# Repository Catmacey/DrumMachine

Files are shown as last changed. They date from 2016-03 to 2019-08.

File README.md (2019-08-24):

16 step sample based DrumMachine
================================

DrumMachine

[Demo of features (Youtube)](https://www.youtube.com/watch?v=TWu0VHxkMRI)

This is a 16 track Sample based Drum Machine built on a 32bit PIC (PIC32mx150f128b).

The project hardware is relatively simple in that it limits itself to using the PIC's internal Flash for sample storage and the built in OC PWM for output. 

The Drum Machine has 16 tracks (instruments) of 16 steps and can save the song to one of 16 slots on a uSD card.

Features : Updated 24 / 8 / 2019

* 16 different instruments stored in Flash (Length dependant on sample quality/size).
* 16 step patterns with 16 patterns per song.
* 16 songs loaded and saved to FAT formatted uSD card.
* 8 sample polyphony, mixed in software.
* 10bit, 16khz instruments sampled from classic drum machines. (stored as 8bit log similar to uLaw)
* Samples can be "tuned" to playback faster/slower, louder quieter and can also have the in/out points set.
* "Jam Mode" to add some variety to your tracks by fading in/out each track as it plays.
* Swing
* Basic Reverb mode.
* Analog mono output filtered from an 10bit PWM signal.
* 16 buttons for beat input plus 4 more and 4-way joystick for interface.
* 20 leds driven by a Maxim 6957 LED driver to provide feedback.
* [Nokia 1202 B/W LCD](https://github.com/Catmacey/Nokia1202LCD-breakout) mounted on a breakout board displays user interface.
* Songs are stored as plain text in JSON format to allow some human readability.

[More information is available on my blog.](https://catmacey.wordpress.com/tag/drum-machine/)

Copyright (C) 2016 Matt Casey : catmacey.com
This program is free software: you can redistribute it and/or modify it under the terms of the GNU General Public License as published by the Free Software Foundation, either version 3 of the License, or (at your option) any later version.
	
This program is distributed in the hope that it will be useful, but WITHOUT ANY WARRANTY; without even the implied warranty of MERCHANTABILITY or FITNESS FOR A PARTICULAR PURPOSE.  See the GNU General Public License for more details.

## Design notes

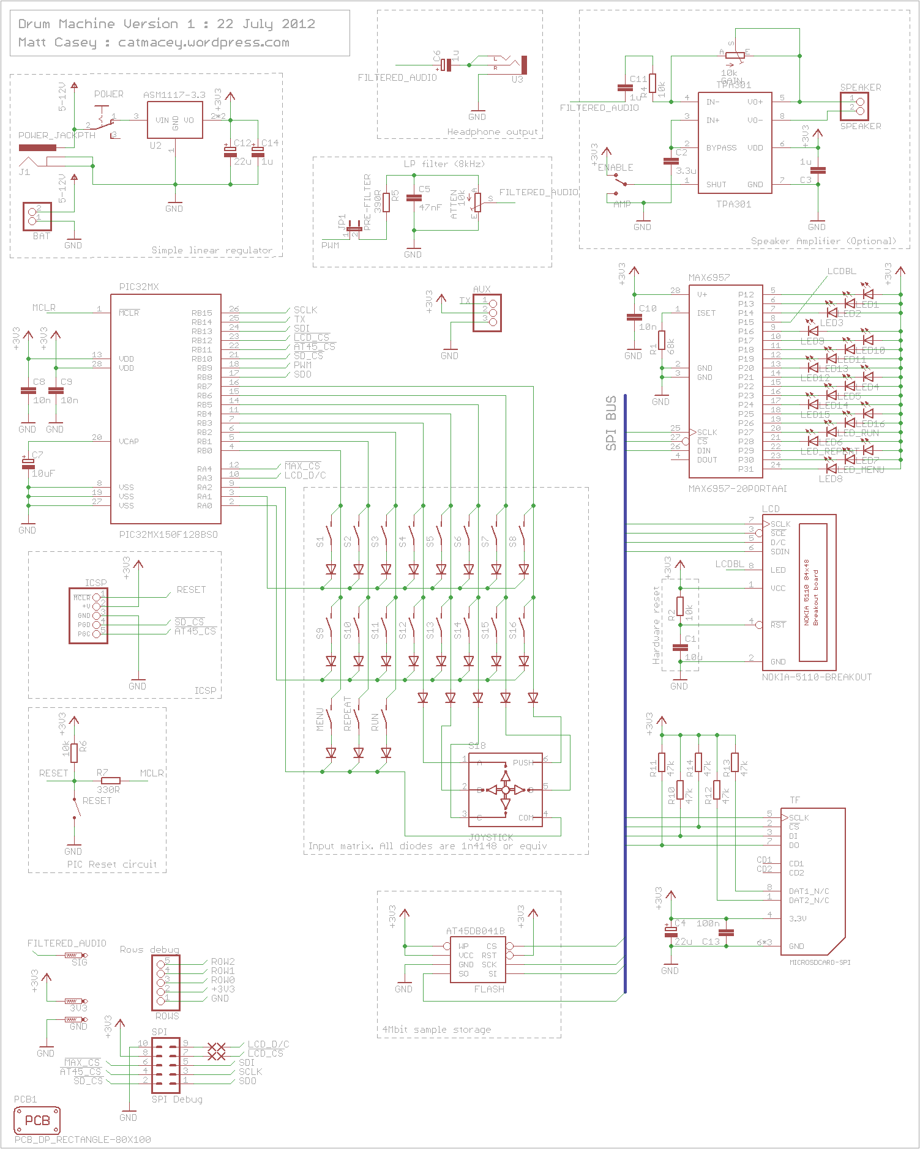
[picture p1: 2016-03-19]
EagleCad/DrumMachine_Pic32_v1.2.Schematic.png

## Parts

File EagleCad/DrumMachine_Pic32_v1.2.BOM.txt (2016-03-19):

Partlist exported from DrumMachine_Pic32_v1.2.sch at 19/03/2016 18:22:23

Part       Value                    Device                   Package                Description                                                   MF MPN OC_FARNELL OC_NEWARK TP_SIGNAL_NAME
3V3        PTR1PAD1-13              PTR1PAD1-13              P1-13                  TEST PIN                                                                                                
AMP        ENABLE                   SWITCH-SPST-SMD-A        SWITCH-SPST-SMD-A      SPST Switch                                                                                             
ATTEN      10k                      TRIM_EU-CA6V             CA6V                   POTENTIOMETER                                                                                           
AUX                                 PINHD-1X3                1X03                   PIN HEADER                                                                                              
BAT                                 PINHD-1X2                1X02                   PIN HEADER                                                                                              
C1         10u                      C-EUC0805                C0805                  CAPACITOR, European symbol                                                                              
C2         3.3u                     C-EUC0805                C0805                  CAPACITOR, European symbol                                                                              
C3         1u                       C-EUC0805                C0805                  CAPACITOR, European symbol                                                                              
C4         22u                      CPOL-EUSMCA              SMC_A                  POLARIZED CAPACITOR, European symbol                                                                    
C5         47nF                     C-EUC0805                C0805                  CAPACITOR, European symbol                                                                              
C6         1u                       CPOL-EU153CLV-0405       153CLV-0405            POLARIZED CAPACITOR, European symbol                                                                    
C7         10uF                     CPOL-EUSMCA              SMC_A                  POLARIZED CAPACITOR, European symbol                                                                    
C8         10n                      C-EUC0805                C0805                  CAPACITOR, European symbol                                                                              
C9         10n                      C-EUC0805                C0805                  CAPACITOR, European symbol                                                                              
C10        10n                      C-EUC0805                C0805                  CAPACITOR, European symbol                                                                              
C11        1u                       C-EUC0805                C0805                  CAPACITOR, European symbol                                                                              
C12        22u                      CPOL-EUSMCA              SMC_A                  POLARIZED CAPACITOR, European symbol                                                                    
C13        100n                     C-EUC0805                C0805                  CAPACITOR, European symbol                                                                              
C14        1u                       CPOL-EU153CLV-0405       153CLV-0405            POLARIZED CAPACITOR, European symbol                                                                    
D1                                  DIODE-SOD-123            SOD-123                Various Diode Packages                                                                                  
D2                                  DIODE-SOD-123            SOD-123                Various Diode Packages                                                                                  
D3                                  DIODE-SOD-123            SOD-123                Various Diode Packages                                                                                  
D4                                  DIODE-SOD-123            SOD-123                Various Diode Packages                                                                                  
D5                                  DIODE-SOD-123            SOD-123                Various Diode Packages                                                                                  
D6                                  DIODE-SOD-123            SOD-123                Various Diode Packages                                                                                  
D7                                  DIODE-SOD-123            SOD-123                Various Diode Packages                                                                                  
D8                                  DIODE-SOD-123            SOD-123                Various Diode Packages                                                                                  
D9                                  DIODE-SOD-123            SOD-123                Various Diode Packages                                                                                  
D10                                 DIODE-SOD-123            SOD-123                Various Diode Packages                                                                                  
D11                                 DIODE-SOD-123            SOD-123                Various Diode Packages                                                                                  
D12                                 DIODE-SOD-123            SOD-123                Various Diode Packages                                                                                  
D13                                 DIODE-SOD-123            SOD-123                Various Diode Packages                                                                                  
D14                                 DIODE-SOD-123            SOD-123                Various Diode Packages                                                                                  
D15                                 DIODE-SOD-123            SOD-123                Various Diode Packages                                                                                  
D16                                 DIODE-SOD-123            SOD-123                Various Diode Packages                                                                                  
D17                                 DIODE-SOD-123            SOD-123                Various Diode Packages                                                                                  
D18                                 DIODE-SOD-123            SOD-123                Various Diode Packages                                                                                  
D19                                 DIODE-SOD-123            SOD-123                Various Diode Packages                                                                                  
D20                                 DIODE-SOD-123            SOD-123                Various Diode Packages                                                                                  
D21                                 DIODE-SOD-123            SOD-123                Various Diode Packages                                                                                  
D22                                 DIODE-SOD-123            SOD-123                Various Diode Packages                                                                                  
D23                                 DIODE-SOD-123            SOD-123                Various Diode Packages                                                                                  
D25                                 DIODE-SOD-123            SOD-123                Various Diode Packages                                                                                  
FLASH      AT45DB041B               AT45DB041B               SO08                                                                                                                           
GAIN       10k                      TRIM_EU-CA6V             CA6V                   POTENTIOMETER                                                                                           
GND        PTR1PAD1-13              PTR1PAD1-13              P1-13                  TEST PIN                                                                                                
ICSP       CON_HEADER_PRG_PIC_ICSPB CON_HEADER_PRG_PIC_ICSPB HEADER_PRG_1X05_ICSP_B 5-pin PIC In Circuit Serial Programming header                                                          
J1         POWER_JACKPTH            POWER_JACKPTH            POWER_JACK_PTH         Power Jack                                                                                              
JP1        PRE-FILTER               JP1E                     JP1                    JUMPER                                                                                                  
LCD        NOKIA-5110-BREAKOUT      NOKIA-5110-BREAKOUT      NOKIA-5110-BREAKOUT                                                                                                            
LED1                                LEDCHIPLED_0805          CHIPLED_0805           LED                                                                                                     
LED2                                LEDCHIPLED_0805          CHIPLED_0805           LED                                                                                                     
LED3                                LEDCHIPLED_0805          CHIPLED_0805           LED                                                                                                     
LED4                                LEDCHIPLED_0805          CHIPLED_0805           LED                                                                                                     
LED5                                LEDCHIPLED_0805          CHIPLED_0805           LED                                                                                                     
LED6                                LEDCHIPLED_0805          CHIPLED_0805           LED                                                                                                     
LED7                                LEDCHIPLED_0805          CHIPLED_0805           LED                                                                                                     
LED8                                LEDCHIPLED_0805          CHIPLED_0805           LED                                                                                                     
LED9                                LEDCHIPLED_0805          CHIPLED_0805           LED                                                                                                     
LED10                               LEDCHIPLED_0805          CHIPLED_0805           LED                                                                                                     
LED11                               LEDCHIPLED_0805          CHIPLED_0805           LED                                                                                                     
LED12                               LEDCHIPLED_0805          CHIPLED_0805           LED                                                                                                     
LED13                               LEDCHIPLED_0805          CHIPLED_0805           LED                                                                                                     
LED14                               LEDCHIPLED_0805          CHIPLED_0805           LED                                                                                                     
LED15                               LEDCHIPLED_0805          CHIPLED_0805           LED                                                                                                     
LED16                               LEDCHIPLED_0805          CHIPLED_0805           LED                                                                                                     
LED_MENU                            LEDCHIPLED_0805          CHIPLED_0805           LED                                                                                                     
LED_REPEAT                          LEDCHIPLED_0805          CHIPLED_0805           LED                                                                                                     
LED_RUN                             LEDCHIPLED_0805          CHIPLED_0805           LED                                                                                                     
MAX6957    MAX6957-20PORTAAI        MAX6957-20PORTAAI        SSOP28                 The MAX6957 is a compact, 4-wire (SPI) interfaced LED display                                           
MENU                                ITT-PTS645SMD            ITT-PTS645SMD          ITT SWITCH                                                                                              
P1         DEBUG_LCD_CS             1,6/0,81.2/0.5           1,2/0,5                THROUGH-HOLE PAD                                                                                        
P1A        LCD CS                   1,6/0,81.2/0.5           1,2/0,5                THROUGH-HOLE PAD                                                                                        
P2         DEBUG_LCD_D/c            1,6/0,81.2/0.5           1,2/0,5                THROUGH-HOLE PAD                                                                                        
P2A                                 1,6/0,81.2/0.5           1,2/0,5                THROUGH-HOLE PAD                                                                                        
PCB1       PCB_DP_RECTANGLE-80X100  PCB_DP_RECTANGLE-80X100  DP10080_V1             Dangerous Prototypes Standard Rectangular PCB sizes                                                     
PIC32MX    PIC32MX150F128BSO        PIC32MX150F128BSO        SO-28                                                                                                                          
POWER                               DX_MINI_SPDT             DX_MINI_SPDT_VERTICAL  SLIDING SWITCH SPDT                                                                                     
R1         68k                      R-EU_R0805               R0805                  RESISTOR, European symbol                                                                               
R2         10k                      R-EU_R0805               R0805                  RESISTOR, European symbol                                                                               
R4         10k                      R-EU_R0805               R0805                  RESISTOR, European symbol                                                                               
R5         390R                     R-EU_R0805               R0805                  RESISTOR, European symbol                                                                               
R6         10k                      R-EU_R0805               R0805                  RESISTOR, European symbol                                                                               
R7         330R                     R-EU_R0805               R0805                  RESISTOR, European symbol                                                                               
R10        47k                      R-EU_R0805               R0805                  RESISTOR, European symbol                                                                               
R11        47k                      R-EU_R0805               R0805                  RESISTOR, European symbol                                                                               
R12        47k                      R-EU_R0805               R0805                  RESISTOR, European symbol                                                                               
R13        47k                      R-EU_R0805               R0805                  RESISTOR, European symbol                                                                               
R14        47k                      R-EU_R0805               R0805                  RESISTOR, European symbol                                                                               
REPEAT                              ITT-PTS645SMD            ITT-PTS645SMD          ITT SWITCH                                                                                              
RESET                               TINY_TACTILESMD          TINY_TACTILE_SMD       DIL/CODE SWITCH                                                                                         
ROWS       Rows debug               PINHD-1X5                1X05                   PIN HEADER                                                                                              
RUN                                 ITT-PTS645SMD            ITT-PTS645SMD          ITT SWITCH                                                                                              
S1                                  ITT-PTS645SMD            ITT-PTS645SMD          ITT SWITCH                                                                                              
S2                                  ITT-PTS645SMD            ITT-PTS645SMD          ITT SWITCH                                                                                              
S3                                  ITT-PTS645SMD            ITT-PTS645SMD          ITT SWITCH                                                                                              
S4                                  ITT-PTS645SMD            ITT-PTS645SMD          ITT SWITCH                                                                                              
S5                                  ITT-PTS645SMD            ITT-PTS645SMD          ITT SWITCH                                                                                              
S6                                  ITT-PTS645SMD            ITT-PTS645SMD          ITT SWITCH                                                                                              
S7                                  ITT-PTS645SMD            ITT-PTS645SMD          ITT SWITCH                                                                                              
S8                                  ITT-PTS645SMD            ITT-PTS645SMD          ITT SWITCH                                                                                              
S9                                  ITT-PTS645SMD            ITT-PTS645SMD          ITT SWITCH                                                                                              
S10                                 ITT-PTS645SMD            ITT-PTS645SMD          ITT SWITCH                                                                                              
S11                                 ITT-PTS645SMD            ITT-PTS645SMD          ITT SWITCH                                                                                              
S12                                 ITT-PTS645SMD            ITT-PTS645SMD          ITT SWITCH                                                                                              
S13                                 ITT-PTS645SMD            ITT-PTS645SMD          ITT SWITCH                                                                                              
S14                                 ITT-PTS645SMD            ITT-PTS645SMD          ITT SWITCH                                                                                              
S15                                 ITT-PTS645SMD            ITT-PTS645SMD          ITT SWITCH                                                                                              
S16                                 ITT-PTS645SMD            ITT-PTS645SMD          ITT SWITCH                                                                                              
S18        JOYSTICK                 ALPS_SKQU_JOYSTICK       ALPS_SKQU_JOYSTICK     4 way mini joystick with center push button                                                             
SIG        PTR1PAD1-13              PTR1PAD1-13              P1-13                  TEST PIN                                                                                                
SPEAKER    SPEAKER                  PINHD-1X2                1X02                   PIN HEADER                                                                                              
SPI        SPI Debug                MA05-2                   MA05-2                 PIN HEADER                                                           unknown    unknown                 
TF         MICROSDCARD-SPI          MICROSDCARD-SPI          TCF001_MICROSD_SOCKET                                                                                                          
TPA301     TPA301                   TPA301                   SO-08                  TPA301 350-mW Mono Class-AB Audio Amplifier                                                             
U2         ASM1117-3.3              ASM1117-3.3              SOT223                 ICP006                                                                                                  
U3                                  AUDIO-JACKPTH            STEREO_JACK3.5MM_PTH   3.5mm Audio Jack

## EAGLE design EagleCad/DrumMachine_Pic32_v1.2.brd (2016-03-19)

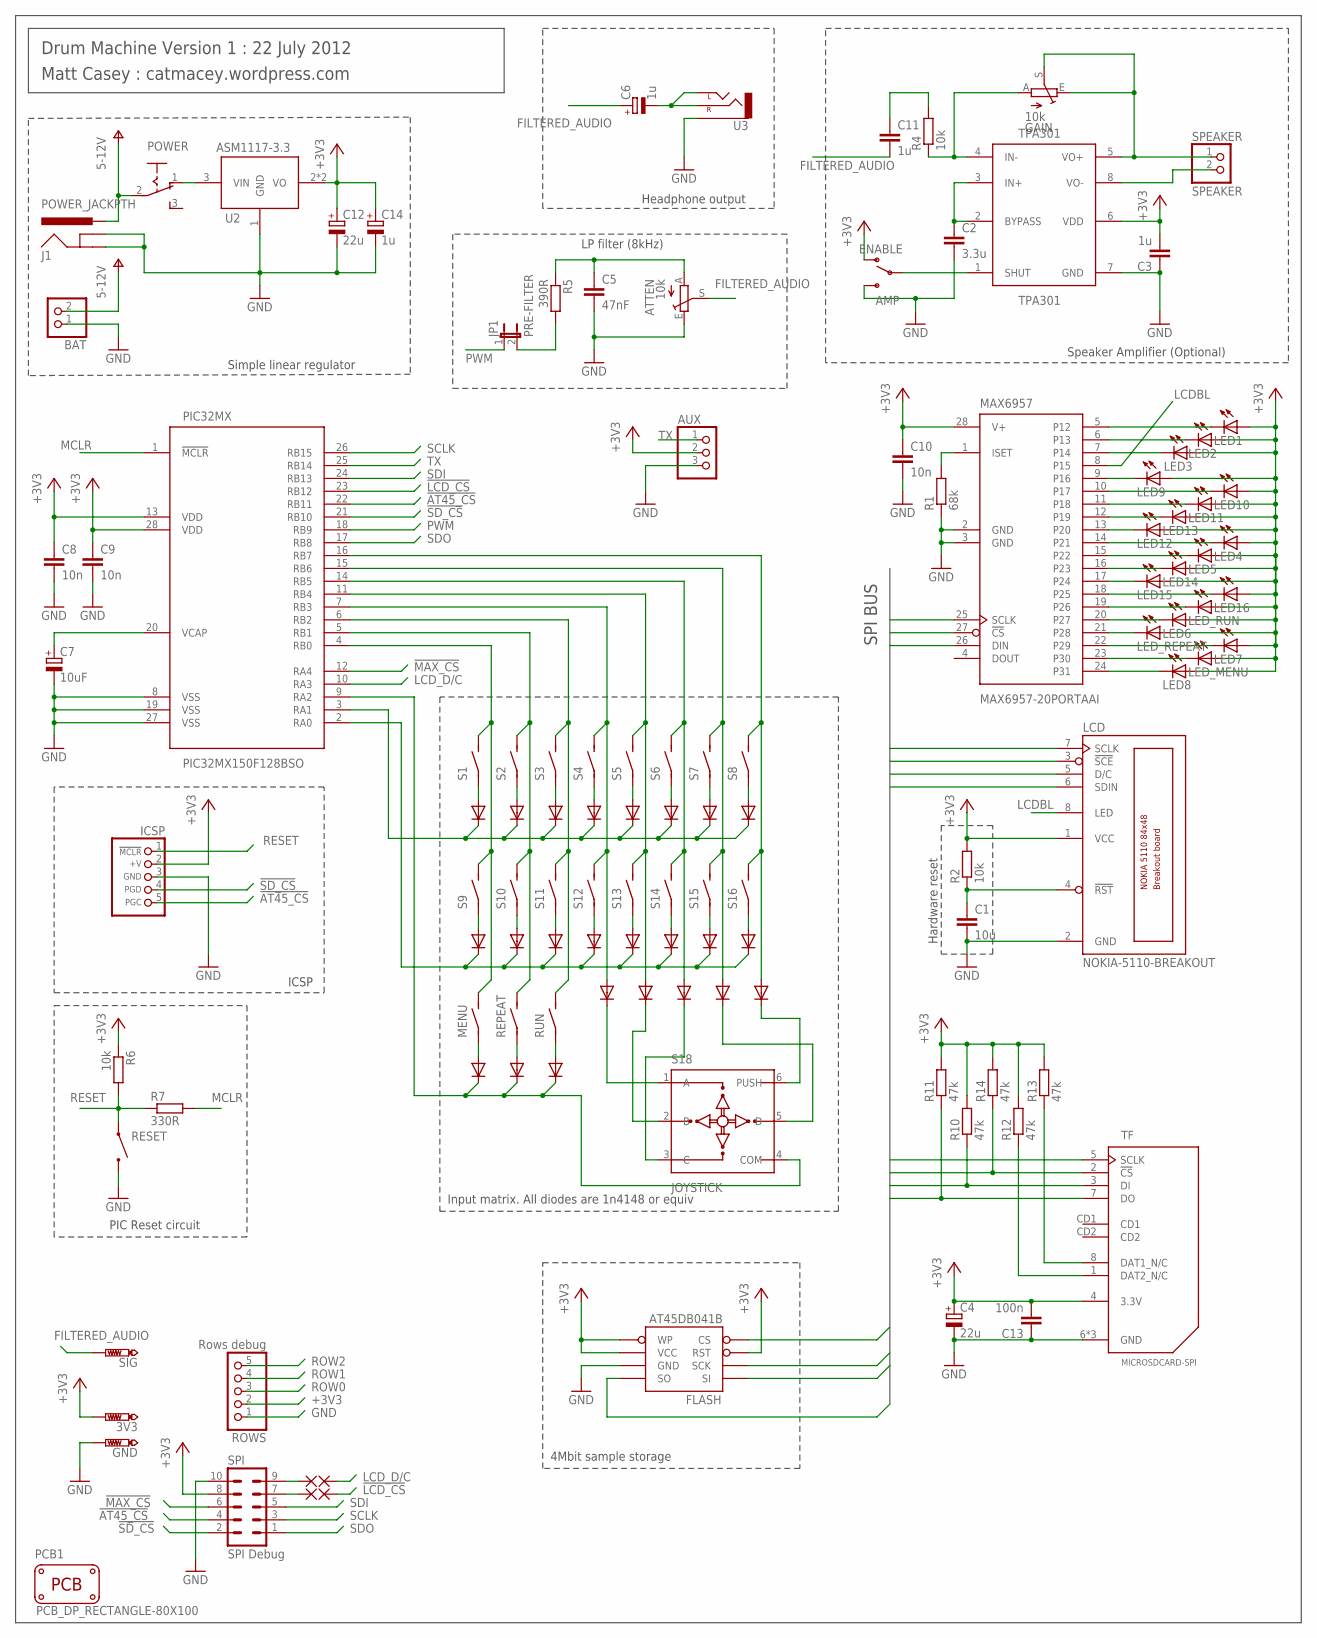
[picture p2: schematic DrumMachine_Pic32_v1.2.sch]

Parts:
3V3: PTR1PAD1-13; P1-13
AMP: ENABLE; SWITCH-SPST-SMD-A
ATTEN: 10k; CA6V
AUX: PINHD-1X3; 1X03
BAT: PINHD-1X2; 1X02
C1: 10u; C0805
C2: 3.3u; C0805
C3, C11: 1u; C0805
C4, C12: 22u; SMC_A
C5: 47nF; C0805
C6, C14: 1u; 153CLV-0405
C7: 10uF; SMC_A
C8, C9, C10: 10n; C0805
C13: 100n; C0805
D1, D2, D3, D4, D5, D6, D7, D8, D9, D10, D11, D12, D13, D14, D15, D16, D17, D18, D19, D20, D21, D22, D23, D25: DIODE-SOD-123; SOD-123
FLASH: AT45DB041B; SO08
GAIN: 10k; CA6V
GND: PTR1PAD1-13; P1-13
ICSP: CON_HEADER_PRG_PIC_ICSPB; HEADER_PRG_1X05_ICSP_B
J1: POWER_JACKPTH; POWER_JACK_PTH
JP1: PRE-FILTER; JP1
LCD: NOKIA-5110-BREAKOUT
LED1, LED2, LED3, LED4, LED5, LED6, LED7, LED8, LED9, LED10, LED11, LED12, LED13, LED14, LED15, LED16: LEDCHIPLED_0805; CHIPLED_0805
LED_MENU: LEDCHIPLED_0805; CHIPLED_0805
LED_REPEAT: LEDCHIPLED_0805; CHIPLED_0805
LED_RUN: LEDCHIPLED_0805; CHIPLED_0805
MAX6957: MAX6957-20PORTAAI; SSOP28
MENU: ITT-PTS645SMD
P1: DEBUG_LCD_CS; 1,2/0,5
P1A: LCD CS; 1,2/0,5
P2: DEBUG_LCD_D/c; 1,2/0,5
P2A: 1,6/0,81.2/0.5; 1,2/0,5
PCB1: PCB_DP_RECTANGLE-80X100; DP10080_V1
PIC32MX: PIC32MX150F128BSO; SO-28
POWER: DX_MINI_SPDT; DX_MINI_SPDT_VERTICAL
R1: 68k; R0805
R2, R4, R6: 10k; R0805
R5: 390R; R0805
R7: 330R; R0805
R10, R11, R12, R13, R14: 47k; R0805
REPEAT: ITT-PTS645SMD
RESET: TINY_TACTILESMD; TINY_TACTILE_SMD
ROWS: Rows debug; 1X05
RUN: ITT-PTS645SMD
S1, S2, S3, S4, S5, S6, S7, S8, S9, S10, S11, S12, S13, S14, S15, S16: ITT-PTS645SMD
S18: JOYSTICK; ALPS_SKQU_JOYSTICK
SIG: PTR1PAD1-13; P1-13
SPEAKER: SPEAKER; 1X02
SPI: SPI Debug; MA05-2
TF: MICROSDCARD-SPI; TCF001_MICROSD_SOCKET
TPA301: TPA301; SO-08
U2: ASM1117-3.3; SOT223
U3: AUDIO-JACKPTH; STEREO_JACK3.5MM_PTH

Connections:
!AT45_CS: FLASH.4 (CS), ICSP.5 (PGC), PIC32MX.22 (RB11), SPI.4
!LCDRST: C1.1, LCD.4 (!RST), R2.1
!LCD_CS: LCD.3 (!SCE), P1.1, P1A.1, PIC32MX.23 (RB12), SPI.7
!MAX_CS: MAX6957.27 (!CS), PIC32MX.12 (RA4), SPI.6
!SD_CS: ICSP.4 (PGD), PIC32MX.21 (RB10), R14.1, SPI.2, TF.2 (!CS)
+3V3: 3V3.TP, AMP.1 (O), AUX.2, C3.2, C4.+, C8.1, C9.1, C10.1, C12.+, C13.2, C14.+, FLASH.3 (RST), FLASH.5 (WP), FLASH.6 (VCC), ICSP.2 (+V), LCD.1 (VCC), LED1.A, LED2.A, LED3.A, LED4.A, LED5.A, LED6.A, LED7.A, LED8.A, LED9.A, LED10.A, LED11.A, LED12.A, LED13.A, LED14.A, LED15.A, LED16.A, LED_MENU.A, LED_REPEAT.A, LED_RUN.A, MAX6957.28 (V+), PIC32MX.13 (VDD), PIC32MX.28 (VDD), R2.2, R6.1, R10.2, R11.2, R12.2, R13.2, R14.2, ROWS.2, SPI.8, TF.4 (3.3V), TPA301.6 (VDD), U2.2 (VO), U2.4 (VO)
COL0: MENU.P$3 (2), MENU.P$4 (2), PIC32MX.4 (RB0), S1.P$3 (2), S1.P$4 (2), S9.P$3 (2), S9.P$4 (2)
COL1: PIC32MX.5 (RB1), REPEAT.P$3 (2), REPEAT.P$4 (2), S2.P$3 (2), S2.P$4 (2), S10.P$3 (2), S10.P$4 (2)
COL2: PIC32MX.6 (RB2), RUN.P$3 (2), RUN.P$4 (2), S3.P$3 (2), S3.P$4 (2), S11.P$3 (2), S11.P$4 (2)
COL3: D19.A, PIC32MX.7 (RB3), S4.P$3 (2), S4.P$4 (2), S12.P$3 (2), S12.P$4 (2)
COL4: D20.A, PIC32MX.11 (RB4), S5.P$3 (2), S5.P$4 (2), S13.P$3 (2), S13.P$4 (2)
COL5: D21.A, PIC32MX.14 (RB5), S6.P$3 (2), S6.P$4 (2), S14.P$3 (2), S14.P$4 (2)
COL6: D22.A, PIC32MX.15 (RB6), S7.P$3 (2), S7.P$4 (2), S15.P$3 (2), S15.P$4 (2)
COL7: D23.A, PIC32MX.16 (RB7), S8.P$3 (2), S8.P$4 (2), S16.P$3 (2), S16.P$4 (2)
FILTERED_AUDIO: ATTEN.S, C6.+, C11.2, SIG.TP
GND: AMP.3 (S), ATTEN.E, AUX.3, BAT.1, C1.2, C2.2, C3.1, C4.-, C5.2, C7.-, C8.2, C9.2, C10.2, C12.-, C13.1, C14.-, FLASH.7 (GND), GND.TP, ICSP.3 (GND), J1.GND, J1.GNDBREAK, LCD.2 (GND), MAX6957.2 (GND), MAX6957.3 (GND), PIC32MX.8 (VSS), PIC32MX.19 (VSS), PIC32MX.27 (VSS), R1.1, RESET.2 (B), ROWS.1, SPI.10, TF.6 (GND), TF.P$11 (GND), TF.P$12 (GND), TPA301.7 (GND), U2.1 (GND), U3.S (SLEEVE), U3.S@1 (SLEEVE)
LCDBL: LCD.8 (LED), MAX6957.8 (P15)
LCD_D/C: LCD.5 (D/C), P2.1, P2A.1, PIC32MX.10 (RA3), SPI.9
MCLR: PIC32MX.1 (!MCLR), R7.2
unnamed: D25.A, S1.P$1 (1), S1.P$2 (1)
unnamed: D1.A, S2.P$1 (1), S2.P$2 (1)
unnamed: D2.A, S3.P$1 (1), S3.P$2 (1)
unnamed: D3.A, S4.P$1 (1), S4.P$2 (1)
unnamed: D4.A, S5.P$1 (1), S5.P$2 (1)
unnamed: D5.A, S6.P$1 (1), S6.P$2 (1)
unnamed: D6.A, S7.P$1 (1), S7.P$2 (1)
unnamed: D7.A, S8.P$1 (1), S8.P$2 (1)
unnamed: LED1.C, MAX6957.5 (P12)
unnamed: LED2.C, MAX6957.6 (P13)
unnamed: LED3.C, MAX6957.7 (P14)
unnamed: LED12.C, MAX6957.13 (P20)
unnamed: LED11.C, MAX6957.11 (P18)
unnamed: LED10.C, MAX6957.10 (P17)
unnamed: LED9.C, MAX6957.9 (P16)
unnamed: LED4.C, MAX6957.14 (P21)
unnamed: LED13.C, MAX6957.12 (P19)
unnamed: LED14.C, MAX6957.16 (P23)
unnamed: LED15.C, MAX6957.17 (P24)
unnamed: D18.A, MENU.P$1 (1), MENU.P$2 (1)
unnamed: D17.A, REPEAT.P$1 (1), REPEAT.P$2 (1)
unnamed: D16.A, RUN.P$1 (1), RUN.P$2 (1)
unnamed: LED16.C, MAX6957.18 (P25)
unnamed: D19.C, S18.1 (A)
unnamed: D8.A, S9.P$1 (1), S9.P$2 (1)
unnamed: LED5.C, MAX6957.15 (P22)
unnamed: D9.A, S10.P$1 (1), S10.P$2 (1)
unnamed: D10.A, S11.P$1 (1), S11.P$2 (1)
unnamed: D11.A, S12.P$1 (1), S12.P$2 (1)
unnamed: D12.A, S13.P$1 (1), S13.P$2 (1)
unnamed: D13.A, S14.P$1 (1), S14.P$2 (1)
unnamed: D14.A, S15.P$1 (1), S15.P$2 (1)
unnamed: D15.A, S16.P$1 (1), S16.P$2 (1)
unnamed: LED6.C, MAX6957.20 (P27)
unnamed: D20.C, S18.2 (B)
unnamed: D22.C, S18.5 (D)
unnamed: D23.C, S18.6 (PUSH)
unnamed: D21.C, S18.3 (C)
unnamed: LED7.C, MAX6957.22 (P29)
unnamed: LED8.C, MAX6957.24 (P31)
unnamed: LED_RUN.C, MAX6957.19 (P26)
unnamed: LED_REPEAT.C, MAX6957.21 (P28)
unnamed: LED_MENU.C, MAX6957.23 (P30)
unnamed: AMP.2, TPA301.1 (SHUT)
unnamed: MAX6957.1 (ISET), R1.2
unnamed: POWER.1 (O), U2.3 (VIN)
unnamed: C2.1, TPA301.2 (BYPASS), TPA301.3 (IN+)
unnamed: GAIN.E, GAIN.S, SPEAKER.1, TPA301.5 (VO+)
unnamed: C7.+, PIC32MX.20 (VCAP)
unnamed: GAIN.A, R4.1, TPA301.4 (IN-)
unnamed: C11.1, R4.2
unnamed: C6.-, U3.L (LEFT), U3.L@1 (LEFT), U3.R (RIGHT)
unnamed: ATTEN.A, C5.1, R5.1
unnamed: R13.1, TF.8 (DAT1_N/C)
unnamed: R12.1, TF.1 (DAT2_N/C)
unnamed: SPEAKER.2, TPA301.8 (VO-)
PWM: JP1.1, PIC32MX.18 (RB9)
PWM2: JP1.2, R5.2
RESET: ICSP.1 (/MCLR), R6.2, R7.1, RESET.1 (A)
ROW0: D1.C, D2.C, D3.C, D4.C, D5.C, D6.C, D7.C, D25.C, PIC32MX.3 (RA1), ROWS.3
ROW1: D8.C, D9.C, D10.C, D11.C, D12.C, D13.C, D14.C, D15.C, PIC32MX.2 (RA0), ROWS.4
ROW2: D16.C, D17.C, D18.C, PIC32MX.9 (RA2), ROWS.5, S18.4 (COM)
SCLK: FLASH.2 (SCK), LCD.7 (SCLK), MAX6957.25 (SCLK), PIC32MX.26 (RB15), SPI.3, TF.5 (SCLK)
SDI: FLASH.8 (SO), PIC32MX.24 (RB13), R11.1, SPI.5, TF.7 (DO)
SDO: FLASH.1 (SI), LCD.6 (SDIN), MAX6957.26 (DIN), PIC32MX.17 (RB8), R10.1, SPI.1, TF.3 (DI)
TX: AUX.1, PIC32MX.25 (RB14)
V+: BAT.2, J1.PWR, POWER.2

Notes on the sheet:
PIC Reset circuit
ICSP
Speaker Amplifier (Optional)
Headphone output
LP filter (8kHz)
Input matrix. All diodes are 1n4148 or equiv
Hardware reset
Simple linear regulator
Drum Machine Version 1 : 22 July 2012
Matt Casey : catmacey.wordpress.com
SPI BUS
4Mbit sample storage

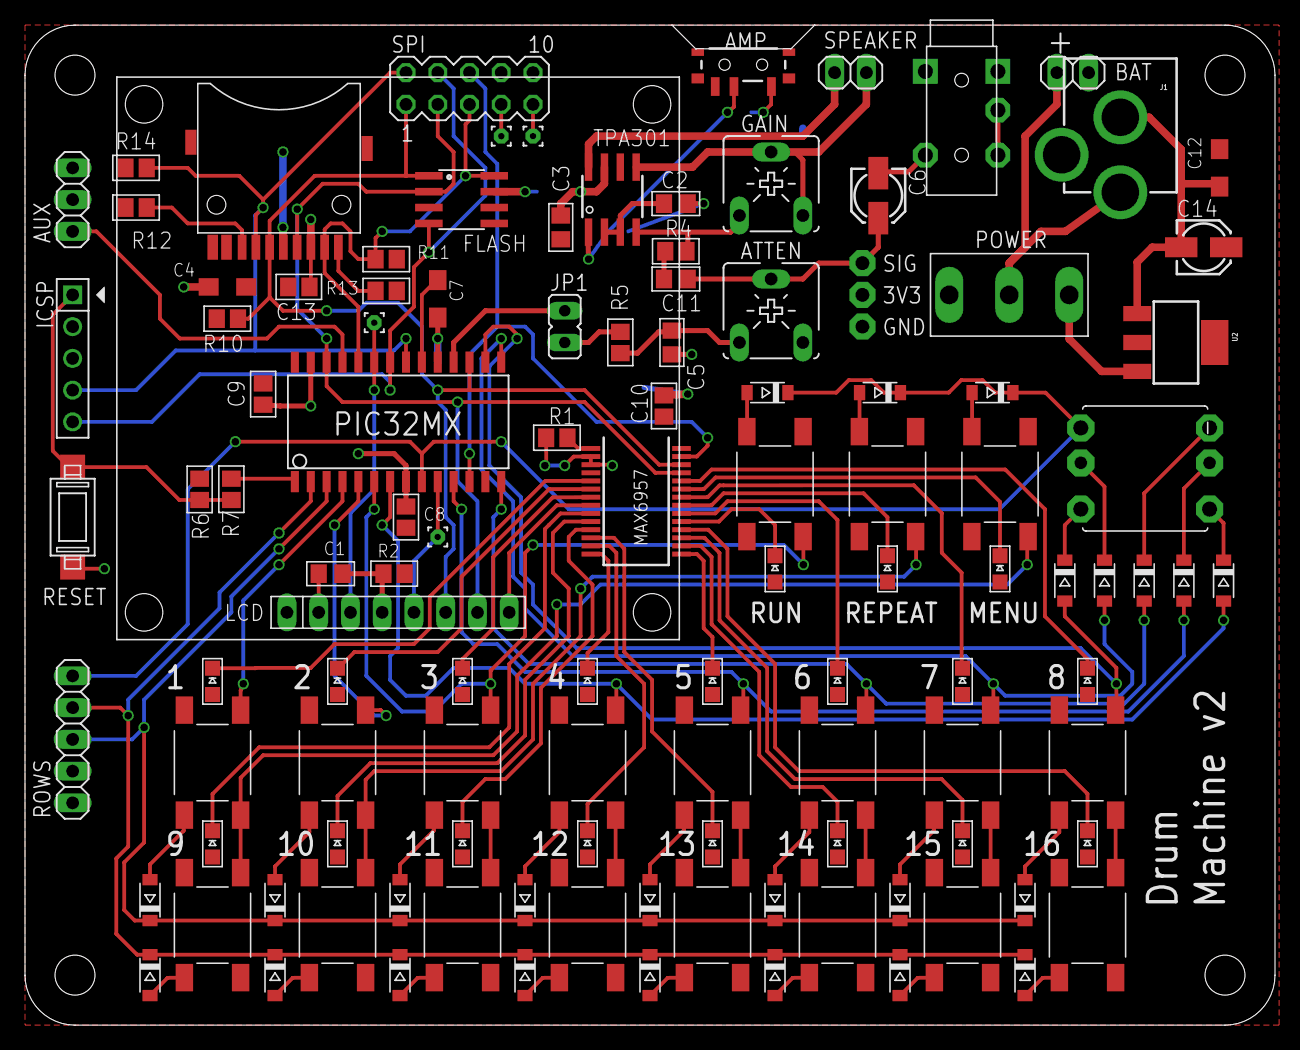
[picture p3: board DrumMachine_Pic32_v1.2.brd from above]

Board: 2 copper layers, 100.0 x 80.0 mm, 117 parts (0 on the bottom side), 86 nets.

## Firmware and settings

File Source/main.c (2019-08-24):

/*
 * PIC32MX150F128B
 * Sample player, sequencer
 * Samples are 8bit signed @16khz
 * Uses MAX6957 to drive LEDs
 * Single 156Khz channel PWM for audio
 * 4 sample polyphony
 * 2x8 matrix for input
 * Loads/Saves up to 16 songs named "song_1.txt" -> "song_16.txt"
*/
#include <xc.h>
#include <plib.h>

// Configuring the Device Configuration Registers
#pragma config JTAGEN = OFF         // Disable JTAG
#pragma config DEBUG    = ON           // Background Debugger
#pragma config ICESEL  = ICS_PGx2       // ISCP Debug pair
#pragma config FWDTEN = OFF             // WD timer: OFF
#pragma config POSCMOD = OFF             // Primary Oscillator Mode
#pragma config FSOSCEN = OFF        // Disable secondary oscillator
#pragma config FPBDIV = DIV_1           // Peripheral Bus Clock: Divide by 1
#pragma config BWP = OFF                // Boot write protect: OFF
#pragma config FNOSC = FRCPLL   // Internal Fast RC oscillator (8 MHz) w/ PLL
/*
	#pragma config FPLLMUL = MUL_20 // PLL Multiply (now 80 MHz)
	#pragma config FPLLODIV = DIV_2 // Divide After PLL (now 40 MHz)
 */
//#pragma config FPLLIDIV = DIV_2 // Divide FRC before PLL (now 4 MHz)
//#pragma config FPLLMUL = MUL_24 // PLL Multiply (now 96 MHz)
//#pragma config FPLLODIV = DIV_2 // Divide After PLL (now 48 MHz)

//#pragma config FPLLIDIV = DIV_2 // Divide FRC before PLL (now 4 MHz)
//#pragma config FPLLMUL = MUL_15 // PLL Multiply (now 60 MHz)
//#pragma config FPLLODIV = DIV_1 // Divide After PLL (now 48 MHz)

#pragma config FPLLIDIV = DIV_2 // Divide FRC before PLL (now 4 MHz)
#pragma config FPLLMUL = MUL_16 // PLL Multiply (now 64 MHz)
#pragma config FPLLODIV = DIV_1 // Divide After PLL (now 48 MHz)


#include <stdlib.h>
#include <string.h>
#include <stdint.h>
#include <stdio.h>
#include "libs/xprintf.h"
#include "fatfs/diskio.h"
#include "fatfs/ff.h"

//#include "splash.h"

//See inside HardwareConfig.h for pin defs
#include "HardwareConfig.h"
// Declare global variables
#include "globals.h"
// Low level SPI routines
#include "SPI.h"
// Loading and saving songs in JSON format to CD card
#include "song_saveload.h"
// Control over the running sequencer
#include "sequencer.h"
// Low level controls for displaying to the LCD
#include "lcd/lcd.h"
// Routines for drawing complex display elements to the LCD
#include "screen.h"
// Handles input/output whilst in menu mode
#include "menumode.h"
// Controls LED display
#include "leds.h"
//Sample data
#include "drumkit.h"

/*
 *	Function prototypes
 */
 
//void timer1Init(void);
//void timer2Init(void);
//void initpic(void);
void bootUp(void);


InputRingBuffer_t gatherInput( void );

//#include "uart1.h"

int main(void){
	InputRingBuffer_t input, previnput;
	uint8_t idx = 0;
	uint8_t patternIdx = 15;
	uint8_t trackIdx = 15;
	uint8_t step = 15;
	uint8_t stepon = 0;
	uint8_t bpm = 0;
	int8_t result = 0;

	// Temp vars for tests
//	int8_t tdx = 0;
//	uint16_t adx = 0;
//	uint16_t bdx = 0;

	bootUp();

	mPORTBRead();

  _LATB14 = 1;

	//Set default output for prints
	xdev_out(lcd_putChar);

	setLEDstate(LCD_BL, ON);

	// Debug : Clear terminal screen
	puts("\033[2J");
	printf("Ready to go!");
  _LATB14 = 1;

	lcd_setCursor(0,0);
	lcd_putStr("Boot");

	g_systemState.complete = 0x0000;

	//NOTE set g_systemState.trackChange to trigger display of track/step on first run rather than
	//Current technique of setting pattern step and tracks to false values (15)

	//Stop the sequencer
	seq_stop();
	bpmSetTmr();

	lcd_setCursor(0,0);
	lcd_putStr("Drumkit Ready");
	lcd_render();
	
	idx = 0x80;
	// Flash the backlight
	while(idx--){
		setLEDintensity(LCD_BL, idx & 0x0f);
		delay_ms(5);
	}
	
	delay_ms(100);
	lcd_clearScreen();
	setLEDintensity(LCD_BL, 0x03);

	//preload g_input to avoid accidental triggering on reset
	for(idx=0; idx<INPUTRINGLEN; idx++){
		g_input[idx].complete = 0xffffffff;
	}
	previnput.complete = 0x00000000;

#ifdef __DEBUG
		//Debug : Add some dummy pattern
		g_song.data[0][0] = 0b0000010100000001;
		g_song.data[0][2] = 0b0001000000010000;
    //g_song.data[0][2] = 0b0101010101010101;
    //g_song.data[0][3] = 0b1111000011110000;
		g_systemState.repeat = 0b1;
		seq_run();
	#endif

	//Setup some volumes and directions for each track for jammode
	for(idx=0; idx <= TRACKCOUNT; idx++){
		g_jammode[idx].volume = 0;
		g_jammode[idx].voldir = 1;
	}


	// Messing with the default rates
	for(idx=0; idx <= CHANNELCOUNT; idx++){
		g_song.rate[idx] = RATE_DEFAULT;
		g_song.inpoint[idx] = 0;
		if(idx <= g_trackCount){
			g_song.outpoint[idx] = g_waveformLen[idx];
		}
	}//for


  _LATB14 = 0;

	//Enable Timer 1 interupt : Handles PWM loading and sample mixing
	EnableIntT1;
	//Enable Timer 4 interupt : Handles input
	EnableIntT4;

	// Test of volume drawing
	/*
	tdx = VOLUME_MIN;
	for(idx=0; idx<=TRACKCOUNT; idx++){
		g_song.volume[idx] = tdx;
		tdx+=2;
	}
	*/
	//lcd_clearScreen();

	//Main
	while(1){
//		setLEDstate(LCD_BL, ON);

//		mPORTBToggleBits(BIT_11);

		//Process the input ring buffer
		input = gatherInput();

		if(input.complete != previnput.complete){
			/*
			 * State is different to last time!
			 * Do something!
			 */

			// lcd_setCursor(0,0);
			// xprintf("S :%4x", input.buttons);

			//Important stuff first
			if(input.run) 		seq_toggle();
			if(input.menu) 		toggleMenu();
			if(input.repeat) 	seq_toggleRepeat();

			if(g_systemState.patternedit){
				// Do something...
			}else if(g_systemState.songload || g_systemState.songsave){
				g_systemState.menu = 1;
				if(input.menu){
					result = 1;
				}else{
					result = song_loadOrSave(g_systemState.songload, &input);
				}
				if(result){
					lcd_clearBuffer();
					g_systemState.songload = 0;
					g_systemState.songsave = 0;
					g_systemState.trackchange = 1;
					// Pretend to be in menu mode in order to come out of it.
					toggleMenu();
				}
			}else if(g_systemState.menu){
				// Catch menu after other modes that pretend to be a menu
				menu_main(input, previnput);
			}else{
				// Not menu mode
				if(input.up)			trackPrev();
				if(input.down)		trackNext();
				if(g_systemState.running){
					//Things we can do with running
					if(input.right) bpmUp();
					if(input.left)	bpmDown();
				}else{
					//Things to do whilst stopped
					if(input.right) patternNext();
					if(input.left)	patternPrev();
				}
				/*
				 * Dealing with the step buttons
				 */
				if(input.steps > 0 && input.steps != previnput.steps){
					//Step buttons set the beats
					g_song.data[g_song.pattern][g_song.track] ^= input.steps;
					g_song.modified = 1;
					if(!g_systemState.running){
						//play note if not running
						g_channel[0].position = (uint32_t)g_song.inpoint[g_song.track] << 8;  // Position is 24:8 fractional
						g_channel[0].instrument = g_song.track;
						g_channel[0].volume = g_song.volume[g_song.track];
						g_channel[0].rate = g_song.rate[g_song.track];
					}
					g_systemState.trackchange = 1;
				}
			}

			//Copy state over to prevstate for comparison next iter
			previnput = input;
		}//if

		/*
			Every loop
		*/


		//Display pattern/track data
		if(
				patternIdx != g_song.pattern
				|| trackIdx != g_song.track
				|| g_systemState.trackchange
		){
			//Display the current pattern/track on the LEDs
//			printf("Render pattern, %u, %u, %u", g_song.pattern, g_song.track, g_systemState.trackchange);
			patternIdx = g_song.pattern;
			trackIdx = g_song.track;
			led_displayPattern();
			if(!g_systemState.menu){
				displayPatternTrackCounters();
				displayPatternGraph(g_systemState.jamming?0:1);
			}
			g_systemState.trackchange = 0;
		}

		//Display BPM
		if(bpm != g_song.bpm && !g_systemState.menu){
			bpm = g_song.bpm;
			displayBPM();
		}

		if(step != g_song.step){
			step = g_song.step;
			//Step change
			if(!g_systemState.menu){
				displayStep();
				if(g_systemState.jamming){
					//Display the current track volumes
					displayTrackVolumes(49,19,-1);
				}
			}
			//Update the LEDs if running
			if(g_systemState.running){
				led_displayStepOn(step);
				// Run LED counts out the beat
				if((g_song.step & 0b00000011) == 0) setLEDintensity(RUN, 15);
				stepon = 1;
			}
		}
		if(stepon && (TMR2 > 3125)){
			//relies upon tmr2 being reset on each step
			//3125 is 50ms at TMR rate
			led_displayStepOff(step);
			if((g_song.step & 0b00000011) == 0) setLEDintensity(RUN, LED_INTENSITY_DEFAULT);
			stepon = 0;
		}
		//mPORTBToggleBits(BIT_14);

		// Render to screen : Might not send anything if no change in buffer
		lcd_render();
		// Maybe rather than just delaying here it would be better to look at a timer to decide how long to wait in order to keep a reasonably constant "frame rate"
		delay_ms(3);
	}//while

}//func


/*
 * Gathers input from the global input buffer.
 * Returns an input stuct
 */
InputRingBuffer_t gatherInput( void ){
	InputRingBuffer_t input;
	int8_t idx = 0;
	input.complete = 0x00000000;
	// We end up with a struct containing the debounced state of the buttons
	for(idx=0; idx<INPUTRINGLEN; idx++){
		input.complete = input.complete | g_input[idx].complete;
	}
	/*
	 * Now we have the buttons states OR'd together
	 * Any pressed button should be a zero.
	 * Active buttons are low so invert them to get a 1 for a pushed button
	 */
	input.complete = ~input.complete;
	return input;
}



/*
General boot up stuff.
Sets IO
*/
void bootUp(void){
	SYSTEMConfig(GetSystemClock(), SYS_CFG_ALL);

	/*
		MX32 have SPI Clk pins hardwired not PPS. 
		USE SPI2 (clk on pin 26)
	*/
	PPSUnLock; //unlock Pin Re-map
	PPSOutput(2,RPB8,SDO2);
	PPSInput(3,SDI2,RPB13);
	PPSOutput(4,RPB9,OC3);
	PPSOutput(4,RPB14,U2TX);
	PPSLock; //lock Pin Re-map

	// enable multi-vector interrupts
  INTEnableSystemMultiVectoredInt();

	//Set all pins as digital
	ANSELA = 0x00000000;
	ANSELB = 0x00000000;
	
	LATA	= 0b1111111111111000;
	LATB	= 0b1111110111111111;
	TRISA = 0b0000000000000000; //1=input, 0=output
	TRISB = 0b0000000011111111; //1=input, 0=output
	CNENA	= 0; //No change ints
	CNENB	= 0; //No change ints
	CNPUB	= 0b0000000011111111; //Enable pullups on portb lower 8 bits

	//Start the core timer with a 1mS tick
	OpenCoreTimer(TICKS_mS);
	mConfigIntCoreTimer(CT_INT_ON | CT_INT_PRIOR_3);

	//Setup the PWM on timer 3
	OpenTimer3(T3_ON | T3_IDLE_STOP | T3_PS_1_1 | T3_SOURCE_INT , 1023);
	OpenOC3( OC_ON | OC_IDLE_STOP | OC_TIMER_MODE16 | OC_TIMER3_SRC | OC_PWM_FAULT_PIN_DISABLE, PWM_duty_zero, PWM_duty_zero );

	//Set up Timer 1 : Fast : Used for mixing the samples and loading the PWM value
	OpenTimer1(T1_ON | T1_SOURCE_INT | T1_PS_1_1, GetSystemClock() / 16000);
	// set up the timer interrupt
	ConfigIntTimer1(T1_INT_PRIOR_5);

	//Setup timer 2 : Runs the sequencer : Slow : around 1 - 4Hz
	OpenTimer2(T2_ON | T2_SOURCE_INT | T2_PS_1_256, 0xffff);
	// set up the timer interrupt
	ConfigIntTimer2(T2_INT_PRIOR_3);

	//Set up Timer 4 : Middling : Used for getting input from the matrix
//	OpenTimer4(T4_ON | T4_SOURCE_INT | T4_PS_1_64, (GetSystemClock()/64) / 3000);
	// set up the timer interrupt
//	ConfigIntTimer4(T1_INT_PRIOR_2);



	//SPI : Mode 3 (CLK Idle high. Dat on rising edge)
	SpiChnOpen(
				SPI_CHANNEL2
			, SPI_OPEN_MSTEN
				| SPI_CONFIG_CKP_HIGH
				| SPI_OPEN_SMP_END
				| SPI_OPEN_MODE8
				| SPI_OPEN_SIDL
				, GetSystemClock()/SPI_SPEED_FAST
		);

		//SPI : Mode 0 (CLK Idle low. Dat on rising edge)
//	SpiChnOpen(
//				SPI_CHANNEL2
//			, SPI_OPEN_MSTEN
//				| SPI_CONFIG_CKE_REV
//				| SPI_OPEN_SMP_END
//				| SPI_OPEN_MODE8
//				| SPI_OPEN_SIDL
//				, GetSystemClock()/SPI_SPEED_FAST
//		);

	//Assign UART1 TX to RP14 (RB14 - pin 25 on a 28 pin dip package)
	
	//UART1Init(103); //9600
	//UART1Init(34); //115200 = 114286  !NOT!
	UARTConfigure(UART2, UART_ENABLE_PINS_TX_RX_ONLY);
  UARTSetFifoMode(UART2, UART_INTERRUPT_ON_TX_NOT_FULL | UART_INTERRUPT_ON_RX_NOT_EMPTY);
  UARTSetLineControl(UART2, UART_DATA_SIZE_8_BITS | UART_PARITY_NONE | UART_STOP_BITS_1);
  //UARTSetDataRate(UART2, GetPeripheralClock(), 57600);
	UARTSetDataRate(UART2, GetPeripheralClock(), 115200);
  UARTEnable(UART2, UART_ENABLE_FLAGS(UART_PERIPHERAL | UART_TX) );

	lcd_Init();

	max6957setup();

	setupSampleTracks();
  loadSamples();
}

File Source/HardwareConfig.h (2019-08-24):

#ifndef _Config_H
#define _Config_H

/******* G E N E R I C   D E F I N I T I O N S ************************************************/

#define BYTETOBINARYPATTERN "%d%d%d%d%d%d%d%d"
#define BYTETOBINARY(byte)  \
  (byte & 0x80 ? 1 : 0), \
  (byte & 0x40 ? 1 : 0), \
  (byte & 0x20 ? 1 : 0), \
  (byte & 0x10 ? 1 : 0), \
  (byte & 0x08 ? 1 : 0), \
  (byte & 0x04 ? 1 : 0), \
  (byte & 0x02 ? 1 : 0), \
  (byte & 0x01 ? 1 : 0) 


#define	HIGH	1
#define	LOW	0
#define	OUTPUT	0
#define	INPUT 	1
//#define	SET	1
//#define	CLEAR	0

//#define GetSystemClock()  (40000000ul)
#define GetSystemClock()  (48000000ul)
//#define GetSystemClock()  (60000000ul)
//#define GetSystemClock()  (64000000ul)
#define GetPeripheralClock()    (GetSystemClock() / (1 << OSCCONbits.PBDIV))
#define TICKS_uS (GetSystemClock() / 1000000)/2   //sys clocks per micro second for core timer
#define TICKS_mS (GetSystemClock() / 1000)/2   //sys clocks per milli second for core timer


//Matrix Columns RB0 - 7
#define Col0 	_RB0
#define Col1 	_RB1
#define Col2 	_RB2
#define Col3 	_RB3
#define Col4 	_RB4
#define Col5 	_RB5
#define Col6 	_RB6
#define Col7 	_RB7

//Matrix Rows RA0 - 1
#define Row0 			_LATA1
#define Row1 			_LATA0
#define Row2 			_LATA2
#define Row0Tris 	_TRISA1
#define Row1Tris 	_TRISA0
#define Row2Tris 	_TRISA2

//PMW out
#define PWM _LATB9

//AT45 RAM CS
#define AT45_CS _LATB11

//Serial debug output
#define TX _LATB14
#define PPS_TX  PPS_RP14

//Spare GPIO (Used to be LCD D/C)
#define DAC_CS _LATA3

//SD Card
#define SD_CS _LATB10
#define SD_CS_ENABLE mPORTBClearBits(BIT_10);
#define SD_CS_CLEAR mPORTBSetBits(BIT_10);

#define SPICHANNEL 2

//NOKIA LCD PORT PIN DEFINTION
///****************************************************
// Hardware SPI
// Manual CS between each byte, but could be modified to do bulk transfers.
///****************************************************
#define LCD_CS 		_LATB12

#define LCD_CS_ENABLE() mPORTBClearBits(BIT_12)
#define LCD_CS_CLEAR() mPORTBSetBits(BIT_12)

#define SPI_CLK_HIGH() mPORTBSetBits(BIT_15)
#define SPI_CLK_LOW() mPORTBClearBits(BIT_15)

#define SPI_MOSI_HIGH() mPORTBSetBits(BIT_8)
#define SPI_MOSI_LOW() mPORTBClearBits(BIT_8)


//#define LCD_RST 	_LATB12 //Can be performed in hardware with R/C. saves pin

//#define LCD_BL 		_LATB9 //LED backlight PWM'd

//MAX6957
///****************************************************
// Hardware SPI
// Manual CS between each byte, but could be modified to do bulk transfers.
///****************************************************
#define MAX6957_CS 		_LATA4

#define LCDTYPE_NOKIA_1202


#endif

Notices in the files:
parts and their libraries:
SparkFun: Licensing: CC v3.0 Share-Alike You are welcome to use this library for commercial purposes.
